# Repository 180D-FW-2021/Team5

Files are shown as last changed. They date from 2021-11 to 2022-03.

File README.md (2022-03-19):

# beep boop want to drive
**ECE 180D Team 5**: Derrick Huynh, David Kao, Robert Peralta, Lucas Wolter

## Overview
Beep boop want to drive is a reincarnation of the classic game
[Snake](https://en.wikipedia.org/wiki/Snake_(video_game_genre)), aiming to
bridge the gap between software and hardware in an engaging and entertaining
game. In beep boop want to drive, the user wirelessly steers a hardware car,
which they navigate around a game arena marked out in tape. There are several
dots placed in the arena and the user is directed to random dots in turn. The
user is provided 3 powerups, which they can use to cut the speed of the car in
half for 3 seconds, gaining a new powerup every 5 dots collected. Picking up a
dot increases the speed of the car up to maximum speed after 8 dots. The goal of
the game is to collect as many dots as possible without leaving the arena 3
times.

The game features a hardware, remote-controlled car, gesture recognition
steering, speech recognition game controls, and an overhead camera that uses
computer vision to track the game. A central laptop orchestrates the entire
game, seamlessly blending the disjoint modules together.

## Setup with Provided Hardware

### Game Arena

Take a white poster board and give it a border of black tape, leaving about a
1/2 inch gap between the tape and the edge of the poster board. Cut 4-5 squares
from a piece of black construction paper and tape them to the poster. Affix the
poster to the floor. Position the external camera directly over the poster such
that the entire poster is comfortably in view.

### Car

Make sure the `wpa_supplicant.conf` file is up to date with the wifi network and
password it will be using. Plug the power bank into the RPi and get its IP
address with

```
ping -4 raspberrypi.local
```

Then remotely `ssh` into the RPi and run the script:

```
ssh pi@<IP Address>
conda activate controller
python Team5/hardware/startCar.py
```
You can test if this is successful when running the main controller and having a successful handshake.

### IMU

Make sure the `wpa_supplicant.conf` file is up to date with the wifi network and
password it will be using. Attach the IMU RPi to the computer and log into it
with a serial connection. The necessary script will start automatically. Press
Ctrl+C to stop the script after finishing the game. If you need to restart the
script, run the following commands:

    cd Team5/gesture/BerryIMU/python-BerryIMU-gyro-accel-compass-filters
    python berryIMU.py

### Game Controller

Set up the controller environment with the following commands:

```
git clone https://github.com/180D-FW-2021/Team5.git
cd Team5/controller
conda env create -f environment.yml
conda activate controller
```
Then, ensuring that the external webcam is attached to the computer and
functional, find the computer's device handle indices with

```
python start.py --show-devices
```

To determine which of the listed camera indices is the correct one, test them
with commands like

```
python start.py --test-camera --camera <INDEX>
```

After finding the correct camera and microphone indices, start the game with

```
python start.py --camera <INDEX> --microphone <INDEX>
```

---
For full setup instructions and technical details, see the User Manual in
[`docs/README.md`](./docs/README.md).

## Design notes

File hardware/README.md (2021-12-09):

# Hardware
Code related to controlling and running the car

## `Car.__init__(in1, in2, in3, in4, enL, enR)`
The constructor of the `Car` class takes 6 parameters for the 4 input pins, and the 2 enable pins. The input pins control the direction of the motor and the enable pins control the speed.

Note: The enable pins MUST be PWM. On RPi, PWM are pins 12,13,18,19.

## `MQTT Commands`
### topic = `ece180d/team5/motorControls`

payload:

'L' - turns car left

'R' - turns car right

it works by running the motors in a different direction in a while loop for left(right)_turn_length seconds. This is a WIP as the length needs to be a function of the speed
after running in different direction, it then outputs the in pins to drive straight.

### topic = `ece180d/team5/speed`
the speed can only be between [20, 100]

payload:

'+' - increases the speed by 10%

'-' - decreases the speed by 10%

'#' (20 <= # <= 100) - sets custom speed at #%

### topic = `ece180d/team5/game`
Controls game functions

payload:

'game over' - stops the game and ends the script

'stop car' - stops the car and disables inputs (L/R)

'start car' - restarts car at previous speed

'activate power' - activates powerup that sets the speed to half the current speed. After 3 seconds, it returns to the old speed.

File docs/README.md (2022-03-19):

# User Manual
**ECE 180D Team 5**: Derrick Huynh, David Kao, Robert Peralta, Lucas Wolter

## Contents
1. [Overview](#overview)
1. [How to Play](#how-to-play)
1. [Setup with Provided Hardware](#setup-with-provided-hardware)
1. [Detailed Setup](#detailed-setup)

## Overview
Beep boop want to drive is a reincarnation of the classic game
[Snake](https://en.wikipedia.org/wiki/Snake_(video_game_genre)), aiming to
bridge the gap between software and hardware in an engaging and entertaining
game. In beep boop want to drive, the user wirelessly steers a hardware car,
which they navigate around a game arena marked out in tape. There are several
dots placed in the arena and the user is directed to random dots in turn. The
user is provided 3 powerups, which they can use to cut the speed of the car in
half for 3 seconds, gaining a new powerup every 5 dots collected. Picking up a
dot increases the speed of the car up to maximum speed after 8 dots. The goal of
the game is to collect as many dots as possible without leaving the arena 3
times.

The game features a hardware, remote-controlled car, gesture recognition
steering, speech recognition game controls, and an overhead camera that uses
computer vision to track the game. A central laptop orchestrates the entire
game, seamlessly blending the disjoint modules together.

## How to Play

* Hold the IMU controller with the USB cable pointing away from you. Tilt it
  left and right to steer. The car will only turn by a set amount
* Use voice commands to control the game:
    * `game pause`: stop the car and pause the game
    * `continue`: continue the game from a paused state
    * `activate power`: use a powerup, slowing the car down for a limited time
* Drive over the dot outlined in purple on the GUI to pick it up
* Every dot will increase the car's speed, and every 5 will give a new powerup
* If the car leaves the arena, you lose a life and game is paused. Move the car
  back into the arena and say `continue` to continue the game

## Setup with Provided Hardware

### Game Arena

Take a white poster board and give it a border of black tape, leaving about a
1/2 inch gap between the tape and the edge of the poster board. Cut 4-5 squares
from a piece of black construction paper and tape them to the poster. Affix the
poster to the floor. Position the external camera directly over the poster such
that the entire poster is comfortably in view.

### Car

Make sure the `wpa_supplicant.conf` file is up to date with the wifi network and
password it will be using. Plug the power bank into the RPi and get its IP
address with

```
ping -4 raspberrypi.local
```

Then remotely `ssh` into the RPi and run the script:

```
ssh pi@<IP Address>
conda activate controller
python Team5/hardware/startCar.py
```
You can test if this is successful when running the main controller and having a successful handshake.

### IMU

Make sure the `wpa_supplicant.conf` file is up to date with the wifi network and
password it will be using. Attach the IMU RPi to the computer and log into it
with a serial connection. The necessary script will start automatically. Press
Ctrl+C to stop the script after finishing the game. If you need to restart the
script, run the following commands:

    cd Team5/gesture/BerryIMU/python-BerryIMU-gyro-accel-compass-filters
    python berryIMU.py

### Game Controller

Set up the controller environment with the following commands:

```
git clone https://github.com/180D-FW-2021/Team5.git
cd Team5/controller
conda env create -f environment.yml
conda activate controller
```
Then, ensuring that the external webcam is attached to the computer and
functional, find the computer's device handle indices with

```
python start.py --show-devices
```

To determine which of the listed camera indices is the correct one, test them
with commands like

```
python start.py --test-camera --camera <INDEX>
```

After finding the correct camera and microphone indices, start the game with

```
python start.py --camera <INDEX> --microphone <INDEX>
```

## Detailed Setup
The game has 3 computers which all require different software running on them: the RPi with the IMU, the RPi on the car, and the controlling laptop. In total, you will need the following:

* Laptop (1)
* External webcam or smartphone (1)
  * If using a phone, you will need a camera mount to hold the phone over the game arena
* RaspberryPi Zero WH (2)
* BerryIMUv3 (1)
* 9V Battery
* 5V battery powerbank
* Hardware car
* White poster board
* Black paper (try to use non-reflective materials for all computer vision)
* Miscellaneous wires and connectors (Recommended to have ~8 Female-Male) OR a perfboard soldered with all necessary connections.

Note that the hardware car is not described in detail here. Currently we have no schematic of the car to share, but the car is based on an [L293 H-bridge](https://www.adafruit.com/product/807) and 2 9V DC motors, and an industrious user could investigate the code in the `hardware` directory to determine pin assignments on the RPi. Refer to the following info on how the H–Bridge works: [Direction Truth Table](https://drive.google.com/file/d/1n0UCoyRyvaSpgobGnBY8AHq8t6nLdRKh/view?usp=sharing), [H-Bridge Pinout](https://drive.google.com/file/d/1lcsleWE-I3sc4Y-wqP7EvscM3ZZQUWd-/view?usp=sharing).

### Arena
The arena has 3 main components: the boundary, the dots, and the car. These components are differentiated by their shape and color. The boundary is described by a black inset border on the poster, about a half inch from the edge, the dots are represented by solid black rectangles/squares, and the car is marked with a black circle. For the arena to be valid, there must be a white poster board with its black border, at least two dots, and the car fully within its bounds.

The arena is overseen by the external camera. This can be a standard webcam or a smartphone running [DroidCam](https://www.dev47apps.com/). Since this camera is likely not the default camera of the laptop, one will need to use the startup script described later to determine its device handle to ensure the game runs properly.

### Gesture RPi
These setup instructions are adapted from lab 4.
To setup the IMU controller, first connect the BerryIMU to the Raspberry Pi as shown:
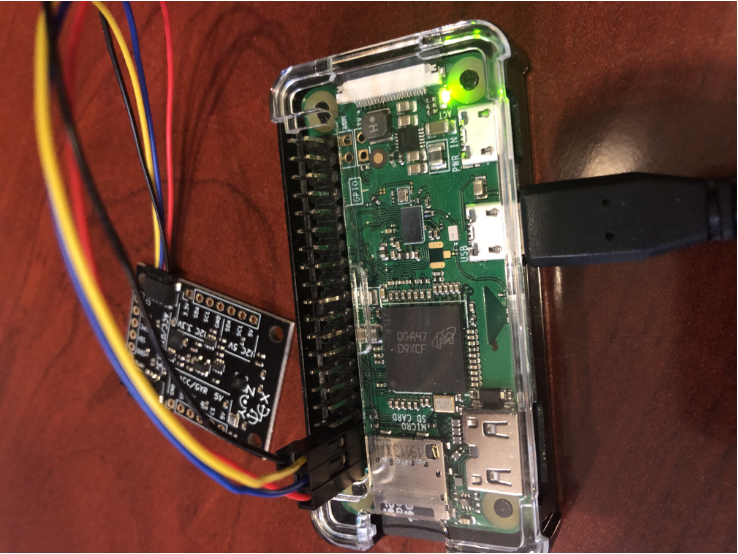
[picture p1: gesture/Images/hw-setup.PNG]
Connection between Raspberry Pi and BerryIMU


Next, enter the following commands into the Raspberry Pi command line to install the necessary components:

    sudo apt-get update
    sudo apt-get upgrade
    conda upgrade conda
    conda update conda
    pip install --upgrade pip
    sudo apt-get install git i2c-tools libi2c-dev
    conda install -c conda-forge smbus2

Try opening the blacklist file `/etc/modprobe.d/raspi-blacklist.conf`. If the file contains the line `blacklist i2c-bcm2708`, place a '#' in front to comment it out. If the file is empty or can't be opened then continue.

Add the following lines into `/etc/modules`:

    i2c-dev
    i2c-bcm2708

Add the following lines into `/boot/config.txt`:

    dtparam=i2c_arm=on
    dtparam=i2c1=on

Reboot the RPi, then enter in the command line `sudo i2cdetect -y 1`. The following should be displayed:
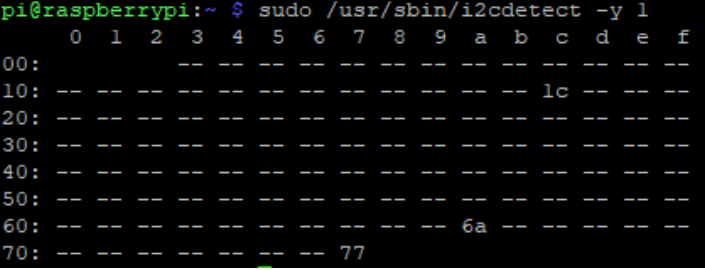
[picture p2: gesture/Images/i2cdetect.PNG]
Correct output for i2cdetect


Next, run `git clone https://github.com/180D-FW-2021/Team5.git` to clone the repository. Run the following commands to navigate to and run the IMU controller code. Always run IMU controller code before running Car RPi code. Press `Ctrl+C` to stop running IMU controller code.

    cd Team5/gesture/BerryIMU/python-BerryIMU-gyro-accel-compass-filters
    python berryIMU.py

### Car RPi
The only set up needed for the Car RPi is to connect to the internet by modifying the `wpa_supplicant.conf` file. Once connected, run `ifconfig` to obtain the IP address under the `WLAN0: inet`. Then enter the settings to enable remote ssh.

Then connect the RPi to the powerbank, then remote ssh and clone the repo.

    ssh pi@<ip address>
    git clone https://github.com/180D-FW-2021/Team5.git
    
Then go to the `Team5/hardware` folder. You may need to modify the file to change any pin assignments and MQTT topics as needed. Note that `enL` and `enR` MUST be PWM pins (pins 12,13,18,19)

    nano mqtt_motor.py
        in1 = ...
        in2 = ...
        etc.
    
The virtual environment provided in `controller/environment.yml` has all necessary packages to run the car software. Follow the steps in the Controller Laptop section to create the same environment on the Car RPi. Then activate the environment and run the main code.
    
    conda activate controller
    python Team5/hardware/startCar.py

Since the `controller` environment contains many large packages that the car will never use, you can also create a simpler environment, including only the `paho-mqtt` package.

    conda create -n <envname> -c conda-forge paho-mqtt
    conda activate <envname>
    python Team5/hardware/startCar.py

1. If your car responds to messages that your controller did not send, make sure that you are not responding to other messages on the same mqtt topic. If this occurs, please change the topic on all MQTT programs. 
2. If you suddenly lose connection to the car, it is possible that the car left the range of the remote ssh. Because of the heartbeat, the car should be perfectly fine running the script remotely and can stop itself. 

### Game Controller
(*This laptop needs a microphone in order to process speech inputs.*)

Follow the instructions in [Setup with Provided Hardware](#setup-with-provided-hardware).

The GUI will display information about the game parts it has parsed. The boundary will be outlined in blue, the dots will have green circles around them, and the car will be outlined in red. The target dot, the next dot the player should aim to get, will have an extra purple circle around it.

The basic GUI is split into two halves. The left half is the camera view, augmented with callouts of the arena boundary, the targets, the current objective, and the location of the car. The right half contains the start button and five text labels. The start button allows the controller to scan the arena and prepare the camera to track the game. The five text labels are, in order: the current game state (running, paused); the player's score, number of lives, number of powerups, and the tooltip. The tooltip changes dynamically based on the current game state. Several of the labels also flash red when appropriate. There are also two buttons at the bottom of the right half that replicate the voice command functions (see `Team5/speech`.) The first one is "continue/pause" and the second one is "activate power."

After the game ends, the GUI will prompt you for your name. Enter your name and go to `beepboopdrive.fun` to view your score on the leaderboard.

Running `start.py` may fail with an error about a license expiring. Because this project uses the free version of [Porcupine](https://picovoice.ai/platform/porcupine/), the speech recognition models eventually expire. If a user so desires, they could train a new model of the same keywords and place the model in `speech/porcupine_models`. The user would also have to change the file paths in [`controller/speechworker.py`](../controller/speechworker.py).

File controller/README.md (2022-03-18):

# Game Controller
Contains the central game controller code. The game controller manages game state and runs the GUI, as well as manages the speech recognition and computer vision modules.

## Speech
The speech recognition module, `speechworker.py` is adapted from the Porucupine demo found in `Team5/speech`. The base paths of the models need to be specified and should be updated monthly because they expire. The access key from Picovoice Console also needs to be provided.

The class inherits from a [PyQt Qthread](https://doc.qt.io/qtforpython/PySide6/QtCore/QThread.html) object to ensure compatibility with the GUI (so it doesn't freeze while listening for keywords). 

## GUI
The GUI uses PyQT5. Install using 

```
pip install PyQt5
```

`cameraworker.py` and `speechworker.py` have been adapted to emit pyqtSignals which don't block threads. This allows them to collect and pass information to the GUI without freezing or crashing the GUI. These signals are passed into "slots", which are similar to event handlers natively attached to GUI elements.

The basic GUI is split into two halves. The left half is the camera view, augmented with callouts of the arena boundary, the targets, the current objective, and the location of the car. The right half contains the start button and five text labels. The start button allows the controller to scan the arena and prepare the camera to track the game. The five text labels are, in order: the current game state (running, paused); the player's score, number of lives, number of powerups, and the tooltip. The tooltip changes dynamically based on the current game state. Several of the labels also flash red when appropriate. There are also two buttons at the bottom of the right half that replicate the voice command functions (see `Team5/speech`.) The first one is "continue/pause" and the second one is "activate power."

After the game ends, the GUI will prompt you for your name. Enter your name and go to `beepboopdrive.fun` to view your score on the leaderboard.



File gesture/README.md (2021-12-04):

# Gesture Recognition
Code related to IMU gesture recognition.

### How to run code:

Download git repository to a Raspberry Pi.

Run the following in terminal:

`cd Team5/gesture/BerryIMU/python-BerryIMU-gyro-accel-compass-filters`

`python berryIMU.py`

Press `Ctrl+C` to stop running the code when finished.

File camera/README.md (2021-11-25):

# Computer Vision
Defines the `Overhead` class in `overhead.py`, which wraps all computer vision functionality. `Overhead` provides functions to find the game boundary and dots, as well as track car motion and detect if the car leaves the boundary or picks up a dot.

## `Overhead.__init__(threshold)`
The constructor of the `Overhead` class takes a single parameter, which is the minimum area for a dot. Any contours of the dot color that have an area smaller than this value will be ignored. Generally, this value is on the order of 100s, but it will depend on the final height of the camera above the game arena.

## `Overhead.setup()`
Parses the game arena, finding the game boundary and all dots in the arena. This only accepts dots that have a contour area greater than the threshold given at construction. `setup()` should only be called once the game arena is set up and the camera is steady. A call to `setup()` will set `self.boundary` with the smoothed contour of the boundary, `self.dots` with a list of bounding circles of the dots found, and `self.nDots` with `len(self.dots)`.

## `Overhead.loop(target)`
The main game loop function, which should be called continuously. `loop()` takes a single parameter: the index of the current target dot. The target index must be between 0 inclusive and `Overhead.nDots` exclusive. The target index is not expected to change until the car collects the dot.

Returns the tuple `(inBoundary, gotTarget)`, where `inBoundary` is `True` if the car is still inside the game boundary and `gotTarget` is `True` if the car has collected the target on this frame. If `gotTarget` is `True`, then the target index should change before the next call to `loop()`.

## `Overhead.drawFrame(target=True, dots=True, car=False, boundary=False)`
Uses OpenCV functions to draw requested objects on the current frame and returns the modified frame in the RGB color space. By default, `drawFrame()` will only include the dots and place an extra circle around the target dot, but it can also draw the car and the game boundary if requested.

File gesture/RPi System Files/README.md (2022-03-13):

These are RPi system files that I edited in an attempt to autostart the IMU script when the RPi powers on.

imu_startup.service is located in /etc/systemd/system/ on the RPi. I was unable to get this service working.

.bashrc is located in /home/pi/ on the RPi. I added the last two lines so the IMU script starts immediately after logging into the RPi.

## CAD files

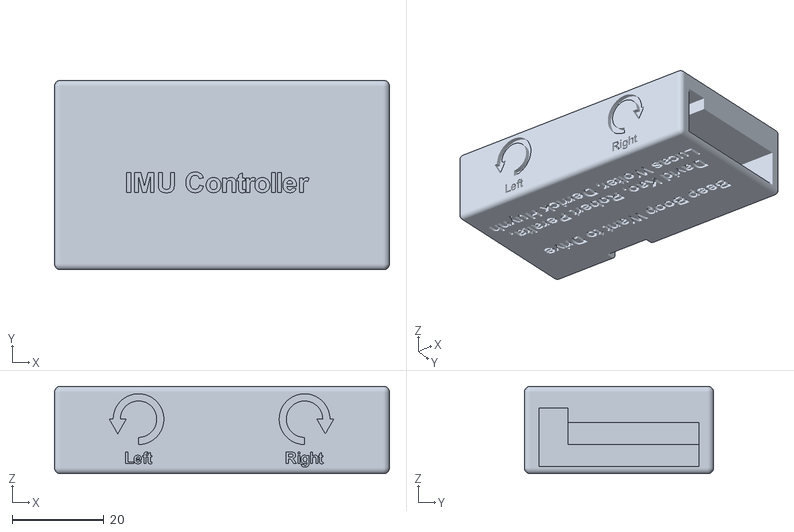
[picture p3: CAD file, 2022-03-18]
gesture/IMU model.stl
73.0 x 41.3 x 19.0

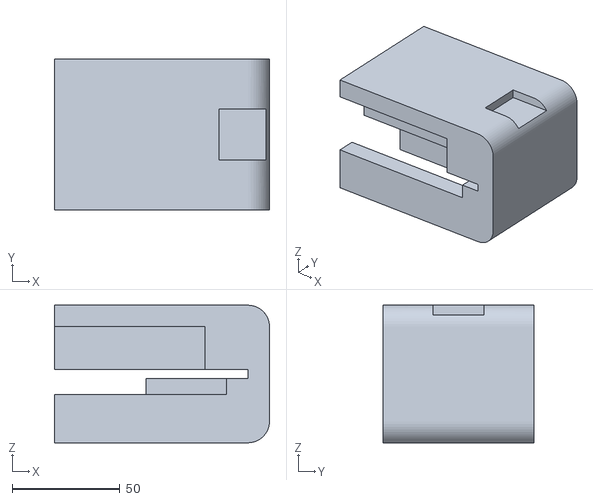
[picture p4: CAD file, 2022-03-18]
hardware/Car Model.stl
100.0 x 70.0 x 64.0

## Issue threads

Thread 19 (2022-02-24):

gui improvements required

davidkao41, 2022-02-24:
1. game end - need popup to input user name
2. info - score, powerups, turns, survived time (game time), current datetime
turns - not super required, but could be fun - needs data from imu
datetime - already implemented in leaderboard
3. turn into json and make http post
in derrick/website/Team5/website/backend/tester.py

derrickkhuynh, 2022-03-03:
#25

last 2 commits of this are what's important.

davidkao41, 2022-03-03:
commited everything besides the turns

davidkao41, 2022-03-13:
ADDED TURNS

Closed 2022-03-13.

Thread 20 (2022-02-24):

restart game from gui

davidkao41, 2022-02-24:
1. need to check if camera/game/mqtt is started in startGame() -> simple check with .active member
2. need to move initialization of game variables into startGame() -> just reset them, still initialize in GUI

Closed 2022-03-02.

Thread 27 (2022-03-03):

Make sure camera doesn't collect dots while game is paused

robertnperalta, 2022-03-03:

Closed 2022-03-13.

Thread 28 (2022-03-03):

GUI crashes on gaining powerup

robertnperalta, 2022-03-03:
Error:

```
Traceback (most recent call last):
  File "C:\Users\rober\Robert\School\UCLA\Year 4\Fall\EE 180D\Team5\controller\controller.py", line 239, in <lambda>
    self.timer.singleShot(1000, lambda x=label: x.setStyleSheet("QLabel {background-color: red;}"))
AttributeError: 'int' object has no attribute 'setStyleSheet'
```

Closed 2022-03-07.

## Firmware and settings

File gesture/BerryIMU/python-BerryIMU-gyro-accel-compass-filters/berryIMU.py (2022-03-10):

#!/usr/bin/python
#
#    This program  reads the angles from the acceleromteer, gyroscope
#    and mangnetometer on a BerryIMU connected to a Raspberry Pi.
#
#    This program includes two filters (low pass and median) to improve the
#    values returned from BerryIMU by reducing noise.
#
#    The BerryIMUv1, BerryIMUv2 and BerryIMUv3 are supported
#
#    This script is python 2.7 and 3 compatible
#
#    Feel free to do whatever you like with this code.
#    Distributed as-is; no warranty is given.
#
#    http://ozzmaker.com/



import sys
import time
import math
import IMU
import datetime
import os


RAD_TO_DEG = 57.29578
M_PI = 3.14159265358979323846
G_GAIN = 0.070          # [deg/s/LSB]  If you change the dps for gyro, you need to update this value accordingly
AA =  0.40              # Complementary filter constant
MAG_LPF_FACTOR = 0.4    # Low pass filter constant magnetometer
ACC_LPF_FACTOR = 0.4    # Low pass filter constant for accelerometer
ACC_MEDIANTABLESIZE = 9         # Median filter table size for accelerometer. Higher = smoother but a longer delay
MAG_MEDIANTABLESIZE = 9         # Median filter table size for magnetometer. Higher = smoother but a longer delay



################# Compass Calibration values ############
# Use calibrateBerryIMU.py to get calibration values
# Calibrating the compass isnt mandatory, however a calibrated
# compass will result in a more accurate heading value.

magXmin =  0
magYmin =  0
magZmin =  0
magXmax =  0
magYmax =  0
magZmax =  0


'''
Here is an example:
magXmin =  -1748
magYmin =  -1025
magZmin =  -1876
magXmax =  959
magYmax =  1651
magZmax =  708
Dont use the above values, these are just an example.
'''
############### END Calibration offsets #################


#Kalman filter variables
Q_angle = 0.02
Q_gyro = 0.0015
R_angle = 0.005
y_bias = 0.0
x_bias = 0.0
XP_00 = 0.0
XP_01 = 0.0
XP_10 = 0.0
XP_11 = 0.0
YP_00 = 0.0
YP_01 = 0.0
YP_10 = 0.0
YP_11 = 0.0
KFangleX = 0.0
KFangleY = 0.0



def kalmanFilterY ( accAngle, gyroRate, DT):
    y=0.0
    S=0.0

    global KFangleY
    global Q_angle
    global Q_gyro
    global y_bias
    global YP_00
    global YP_01
    global YP_10
    global YP_11

    KFangleY = KFangleY + DT * (gyroRate - y_bias)

    YP_00 = YP_00 + ( - DT * (YP_10 + YP_01) + Q_angle * DT )
    YP_01 = YP_01 + ( - DT * YP_11 )
    YP_10 = YP_10 + ( - DT * YP_11 )
    YP_11 = YP_11 + ( + Q_gyro * DT )

    y = accAngle - KFangleY
    S = YP_00 + R_angle
    K_0 = YP_00 / S
    K_1 = YP_10 / S

    KFangleY = KFangleY + ( K_0 * y )
    y_bias = y_bias + ( K_1 * y )

    YP_00 = YP_00 - ( K_0 * YP_00 )
    YP_01 = YP_01 - ( K_0 * YP_01 )
    YP_10 = YP_10 - ( K_1 * YP_00 )
    YP_11 = YP_11 - ( K_1 * YP_01 )

    return KFangleY

def kalmanFilterX ( accAngle, gyroRate, DT):
    x=0.0
    S=0.0

    global KFangleX
    global Q_angle
    global Q_gyro
    global x_bias
    global XP_00
    global XP_01
    global XP_10
    global XP_11


    KFangleX = KFangleX + DT * (gyroRate - x_bias)

    XP_00 = XP_00 + ( - DT * (XP_10 + XP_01) + Q_angle * DT )
    XP_01 = XP_01 + ( - DT * XP_11 )
    XP_10 = XP_10 + ( - DT * XP_11 )
    XP_11 = XP_11 + ( + Q_gyro * DT )

    x = accAngle - KFangleX
    S = XP_00 + R_angle
    K_0 = XP_00 / S
    K_1 = XP_10 / S

    KFangleX = KFangleX + ( K_0 * x )
    x_bias = x_bias + ( K_1 * x )

    XP_00 = XP_00 - ( K_0 * XP_00 )
    XP_01 = XP_01 - ( K_0 * XP_01 )
    XP_10 = XP_10 - ( K_1 * XP_00 )
    XP_11 = XP_11 - ( K_1 * XP_01 )

    return KFangleX


gyroXangle = 0.0
gyroYangle = 0.0
gyroZangle = 0.0
CFangleX = 0.0
CFangleY = 0.0
CFangleXFiltered = 0.0
CFangleYFiltered = 0.0
kalmanX = 0.0
kalmanY = 0.0
oldXMagRawValue = 0
oldYMagRawValue = 0
oldZMagRawValue = 0
oldXAccRawValue = 0
oldYAccRawValue = 0
oldZAccRawValue = 0

a = datetime.datetime.now()



#Setup the tables for the mdeian filter. Fill them all with '1' so we dont get devide by zero error
acc_medianTable1X = [1] * ACC_MEDIANTABLESIZE
acc_medianTable1Y = [1] * ACC_MEDIANTABLESIZE
acc_medianTable1Z = [1] * ACC_MEDIANTABLESIZE
acc_medianTable2X = [1] * ACC_MEDIANTABLESIZE
acc_medianTable2Y = [1] * ACC_MEDIANTABLESIZE
acc_medianTable2Z = [1] * ACC_MEDIANTABLESIZE
mag_medianTable1X = [1] * MAG_MEDIANTABLESIZE
mag_medianTable1Y = [1] * MAG_MEDIANTABLESIZE
mag_medianTable1Z = [1] * MAG_MEDIANTABLESIZE
mag_medianTable2X = [1] * MAG_MEDIANTABLESIZE
mag_medianTable2Y = [1] * MAG_MEDIANTABLESIZE
mag_medianTable2Z = [1] * MAG_MEDIANTABLESIZE

IMU.detectIMU()     #Detect if BerryIMU is connected.
if(IMU.BerryIMUversion == 99):
    print(" No BerryIMU found... exiting ")
    sys.exit()
IMU.initIMU()       #Initialise the accelerometer, gyroscope and compass

############################ MQTT PUBLISHER SETUP ####################

import paho.mqtt.client as mqtt

def on_connect(client, userdata, flags, rc):
	print("Connection returned result: "+str(rc))
	client.subscribe("ece180d/team5/imuReady", qos=1)
	
def on_disconnect(client, userdata, rc):
	if rc != 0:
		print('Unexpected Disconnect')
	else:
		print('Expected Disconnect')

# handshake with game controller to start game		
def on_message(client, userdata, message):
	print('Received message: "' + str(message.payload) + '" on topic "' + message.topic + '" with QoS ' + str(message.qos))
	payload = message.payload.decode("utf-8")
	if payload == '?':
		client.publish(readyString, readyChar, qos=1)

client = mqtt.Client()
client.on_connect = on_connect
client.on_disconnect = on_disconnect
client.on_message = on_message
client.connect_async('test.mosquitto.org')

client.loop_start()

mqttString = 'ece180d/team5/motorControls'
readyString = 'ece180d/team5/imuReady'
turnChar = 'S'
readyChar = 'R'

client.publish(mqttString, turnChar, qos=1)

#########################################################################

while True:

    #Read the accelerometer,gyroscope and magnetometer values
    ACCx = IMU.readACCx()
    ACCy = IMU.readACCy()
    ACCz = IMU.readACCz()
    GYRx = IMU.readGYRx()
    GYRy = IMU.readGYRy()
    GYRz = IMU.readGYRz()
    MAGx = IMU.readMAGx()
    MAGy = IMU.readMAGy()
    MAGz = IMU.readMAGz()


    #Apply compass calibration
    MAGx -= (magXmin + magXmax) /2
    MAGy -= (magYmin + magYmax) /2
    MAGz -= (magZmin + magZmax) /2


    ##Calculate loop Period(LP). How long between Gyro Reads
    b = datetime.datetime.now() - a
    a = datetime.datetime.now()
    LP = b.microseconds/(1000000*1.0)
    outputString = "Loop Time %5.2f " % ( LP )



    ###############################################
    #### Apply low pass filter ####
    ###############################################
    MAGx =  MAGx  * MAG_LPF_FACTOR + oldXMagRawValue*(1 - MAG_LPF_FACTOR);
    MAGy =  MAGy  * MAG_LPF_FACTOR + oldYMagRawValue*(1 - MAG_LPF_FACTOR);
    MAGz =  MAGz  * MAG_LPF_FACTOR + oldZMagRawValue*(1 - MAG_LPF_FACTOR);
    ACCx =  ACCx  * ACC_LPF_FACTOR + oldXAccRawValue*(1 - ACC_LPF_FACTOR);
    ACCy =  ACCy  * ACC_LPF_FACTOR + oldYAccRawValue*(1 - ACC_LPF_FACTOR);
    ACCz =  ACCz  * ACC_LPF_FACTOR + oldZAccRawValue*(1 - ACC_LPF_FACTOR);

    oldXMagRawValue = MAGx
    oldYMagRawValue = MAGy
    oldZMagRawValue = MAGz
    oldXAccRawValue = ACCx
    oldYAccRawValue = ACCy
    oldZAccRawValue = ACCz

    #########################################
    #### Median filter for accelerometer ####
    #########################################
    # cycle the table
    for x in range (ACC_MEDIANTABLESIZE-1,0,-1 ):
        acc_medianTable1X[x] = acc_medianTable1X[x-1]
        acc_medianTable1Y[x] = acc_medianTable1Y[x-1]
        acc_medianTable1Z[x] = acc_medianTable1Z[x-1]

    # Insert the lates values
    acc_medianTable1X[0] = ACCx
    acc_medianTable1Y[0] = ACCy
    acc_medianTable1Z[0] = ACCz

    # Copy the tables
    acc_medianTable2X = acc_medianTable1X[:]
    acc_medianTable2Y = acc_medianTable1Y[:]
    acc_medianTable2Z = acc_medianTable1Z[:]

    # Sort table 2
    acc_medianTable2X.sort()
    acc_medianTable2Y.sort()
    acc_medianTable2Z.sort()

    # The middle value is the value we are interested in
    ACCx = acc_medianTable2X[int(ACC_MEDIANTABLESIZE/2)];
    ACCy = acc_medianTable2Y[int(ACC_MEDIANTABLESIZE/2)];
    ACCz = acc_medianTable2Z[int(ACC_MEDIANTABLESIZE/2)];



    #########################################
    #### Median filter for magnetometer ####
    #########################################
    # cycle the table
    for x in range (MAG_MEDIANTABLESIZE-1,0,-1 ):
        mag_medianTable1X[x] = mag_medianTable1X[x-1]
        mag_medianTable1Y[x] = mag_medianTable1Y[x-1]
        mag_medianTable1Z[x] = mag_medianTable1Z[x-1]

    # Insert the latest values
    mag_medianTable1X[0] = MAGx
    mag_medianTable1Y[0] = MAGy
    mag_medianTable1Z[0] = MAGz

    # Copy the tables
    mag_medianTable2X = mag_medianTable1X[:]
    mag_medianTable2Y = mag_medianTable1Y[:]
    mag_medianTable2Z = mag_medianTable1Z[:]

    # Sort table 2
    mag_medianTable2X.sort()
    mag_medianTable2Y.sort()
    mag_medianTable2Z.sort()

    # The middle value is the value we are interested in
    MAGx = mag_medianTable2X[int(MAG_MEDIANTABLESIZE/2)];
    MAGy = mag_medianTable2Y[int(MAG_MEDIANTABLESIZE/2)];
    MAGz = mag_medianTable2Z[int(MAG_MEDIANTABLESIZE/2)];



    #Convert Gyro raw to degrees per second
    rate_gyr_x =  GYRx * G_GAIN
    rate_gyr_y =  GYRy * G_GAIN
    rate_gyr_z =  GYRz * G_GAIN


    #Calculate the angles from the gyro.
    gyroXangle+=rate_gyr_x*LP
    gyroYangle+=rate_gyr_y*LP
    gyroZangle+=rate_gyr_z*LP

    #Convert Accelerometer values to degrees
    AccXangle =  (math.atan2(ACCy,ACCz)*RAD_TO_DEG)
    AccYangle =  (math.atan2(ACCz,ACCx)+M_PI)*RAD_TO_DEG


    #Change the rotation value of the accelerometer to -/+ 180 and
    #move the Y axis '0' point to up.  This makes it easier to read.
    if AccYangle > 90:
        AccYangle -= 270.0
    else:
        AccYangle += 90.0



    #Complementary filter used to combine the accelerometer and gyro values.
    CFangleX=AA*(CFangleX+rate_gyr_x*LP) +(1 - AA) * AccXangle
    CFangleY=AA*(CFangleY+rate_gyr_y*LP) +(1 - AA) * AccYangle

    #Kalman filter used to combine the accelerometer and gyro values.
    kalmanY = kalmanFilterY(AccYangle, rate_gyr_y,LP)
    kalmanX = kalmanFilterX(AccXangle, rate_gyr_x,LP)

    #Calculate heading
    heading = 180 * math.atan2(MAGy,MAGx)/M_PI

    #Only have our heading between 0 and 360
    if heading < 0:
        heading += 360

    ####################################################################
    ###################Tilt compensated heading#########################
    ####################################################################
    #Normalize accelerometer raw values.
    accXnorm = ACCx/math.sqrt(ACCx * ACCx + ACCy * ACCy + ACCz * ACCz)
    accYnorm = ACCy/math.sqrt(ACCx * ACCx + ACCy * ACCy + ACCz * ACCz)


    #Calculate pitch and roll
    pitch = math.asin(accXnorm)
    roll = -math.asin(accYnorm/math.cos(pitch))


    #Calculate the new tilt compensated values
    #The compass and accelerometer are orientated differently on the the BerryIMUv1, v2 and v3.
    #This needs to be taken into consideration when performing the calculations

    #X compensation
    if(IMU.BerryIMUversion == 1 or IMU.BerryIMUversion == 3):            #LSM9DS0 and (LSM6DSL & LIS2MDL)
        magXcomp = MAGx*math.cos(pitch)+MAGz*math.sin(pitch)
    else:                                                                #LSM9DS1
        magXcomp = MAGx*math.cos(pitch)-MAGz*math.sin(pitch)

    #Y compensation
    if(IMU.BerryIMUversion == 1 or IMU.BerryIMUversion == 3):            #LSM9DS0 and (LSM6DSL & LIS2MDL)
        magYcomp = MAGx*math.sin(roll)*math.sin(pitch)+MAGy*math.cos(roll)-MAGz*math.sin(roll)*math.cos(pitch)
    else:                                                                #LSM9DS1
        magYcomp = MAGx*math.sin(roll)*math.sin(pitch)+MAGy*math.cos(roll)+MAGz*math.sin(roll)*math.cos(pitch)





    #Calculate tilt compensated heading
    tiltCompensatedHeading = 180 * math.atan2(magYcomp,magXcomp)/M_PI

    if tiltCompensatedHeading < 0:
        tiltCompensatedHeading += 360


    ##################### END Tilt Compensation ########################


    if 1:                       #Change to '0' to stop showing the angles from the accelerometer
        outputString += "#  ACCX Angle %5.2f ACCY Angle %5.2f  #  " % (AccXangle, AccYangle)

    if 1:                       #Change to '0' to stop  showing the angles from the gyro
        outputString +="\t# GRYX Angle %5.2f  GYRY Angle %5.2f  GYRZ Angle %5.2f # " % (gyroXangle,gyroYangle,gyroZangle)

    if 1:                       #Change to '0' to stop  showing the angles from the complementary filter
        outputString +="\t#  CFangleX Angle %5.2f   CFangleY Angle %5.2f  #" % (CFangleX,CFangleY)

    if 1:                       #Change to '0' to stop  showing the heading
        outputString +="\t# HEADING %5.2f  tiltCompensatedHeading %5.2f #" % (heading,tiltCompensatedHeading)

    if 1:                       #Change to '0' to stop  showing the angles from the Kalman filter
        outputString +="# kalmanX %5.2f   kalmanY %5.2f #" % (kalmanX,kalmanY)

    print(outputString)

    ############################# MQTT PUBLISH ########################

    # hearbeat
    #client.publish(readyString, readyChar, qos=1)

    if AccXangle < -40 and turnChar != 'L':
        turnChar = 'L'
        client.publish(mqttString, turnChar, qos=1)
    elif AccXangle >= -40 and AccXangle <= 40 and turnChar != 'S':
        turnChar = 'S'
        #client.publish(mqttString, turnChar, qos=1)
    elif AccXangle > 40 and turnChar != 'R':
        turnChar = 'R'
        client.publish(mqttString, turnChar, qos=1)

    ###################################################################

    #slow program down a bit, makes the output more readable
    time.sleep(0.03)

################# MQTT PUBLISHER DISCONNECT ######################

client.loop_stop()
client.disconnect()

####################################################################

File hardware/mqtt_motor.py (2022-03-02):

import paho.mqtt.client as mqtt
import RPi.GPIO as io
import time
from car import Car

game_over = False
powerup_on = False
time_powerup = 0
old_speed = 20

#set up motor pins and en pins. 12,13,18,19 are PWM. We use PWM to control the motor speed on enR and enL.
in1 = 17
in2 = 27
in3 = 23
in4 = 24
enR = 13
enL = 19

car = Car(in1, in2, in3, in4, enR, enL)

def on_connect(client, userdata, flags, rc):
	print("Connection returned result: "+str(rc))

	client.subscribe("ece180d/team5/#", qos=1)

def on_disconnect(client, userdata, rc):
	if rc != 0:
		print("Unexpected Disconnect")
	else:
		print("Expected Disconnect")

def on_message(client, userdata, message):
	global car
	print("Received message:")
	payload = message.payload.decode("utf-8")
	print(payload)
	if(str(message.topic) == 'ece180d/team5/motorControls'):
		if(car.is_stopped == True):
			print('Car is stopped')
		elif(payload == 'L'):
			car.turn_Left()
		elif(payload == 'R'):
			car.turn_Right()
		elif(payload == 'S'):
			pass
		else:
			print('Unknown direction control command')
	elif(str(message.topic) == 'ece180d/team5/speed'):
		if(payload == '+'):
			car.change_Speed(min(car.speed + 10, 100))
		elif(payload == '-'):
			car.change_Speed(max(car.speed - 10, 20))
		else:
			try:
				temp = int(payload)
				if(temp >= 20 and temp <= 100):
					car.change_Speed(temp)
				else:
					print('invalid input speed. It must be between [20, 100]')
			except:
				print('Unknown speed command')
	elif(str(message.topic) == 'ece180d/team5/game'):
		global game_over
		global powerup_on
		global time_powerup
		global old_speed
		if(payload == 'game over'):
			game_over = True
		elif(payload == 'stop car'):
			car.is_stopped = True
			car.stop_Driving()
		elif(payload == 'start car'):
			car.is_stopped = False
			car.start_Driving()
		elif(payload == 'activate power'):
			powerup_on = True
			time_powerup = time.time()
			#grab the old speed before it's changed
			old_speed = car.speed
			#change to speed to half of the old speed (or 20 minimum)
			car.change_Speed(max(old_speed/2, 20))

client = mqtt.Client()

client.on_connect = on_connect
client.on_disconnect = on_disconnect
client.on_message = on_message

#client.connect_async('mqtt.eclipseprojects.io')
client.connect_async('test.mosquitto.org')
client.loop_start()

try:
	while(True):
		while(not(game_over)):
			#if powerup is on, and it's been 3 seconds
			if(powerup_on == True and time.time() - time_powerup >= 3):
				powerup_on = False
				car.change_Speed(old_speed)
				print('Powerup over')
		car.reset()
		game_over = False
		powerup_on = False
		time_powerup = 0
		old_speed = 20
except KeyboardInterrupt:
	io.cleanup()
	client.loop_stop()
	client.disconnect()

io.cleanup()
client.loop_stop()
client.disconnect()

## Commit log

2021-11-11 add porcupine demo + timer
2021-11-11 add speech_recognition demo+timer
2021-11-18 add motor control script
2021-11-18 IMU code
2021-11-18 changed values of motor turning
2021-11-18 add Activate power keyword detection
2021-11-18 add activate power keyword
2021-11-24 Move current frame into a member variable
2021-11-25 add pwm speed control test
2021-11-29 add game conditions (stop/start/over) and powerups
2021-11-30 add activate power command
2021-12-01 Clarify imports for camera worker
2021-12-02 add powerup code
2021-12-02 Add debug prints
2021-12-02 change power up speeds to half current speed
2021-12-03 Only react to camera if game isn't paused
2021-12-04 add test prints
2021-12-05 no longer publishes 'S' on straight movement
    [berryIMU.py]
2021-12-05 Implement powerup
2021-12-05 Re-enable activate-power keyword
2021-12-09 Add None checks on thread shutdown
2022-01-30 change mqtt broker to test.mosquitto.org
    [berryIMU.py]
2022-02-19 Add wrapper to show connected devices
2022-02-19 Print camera indices with names
2022-02-19 Add argument to test camera output
2022-02-19 Update code to pass in device indices
2022-02-24 add reset stuff so car script doesnt end at game over
    [car.py, mqtt_motor.py]
2022-02-24 fix bug w PWM on reset
    [car.py]
2022-02-24 Remove old test print
2022-03-02 issue #22: more powerups
2022-03-03 add IMU ready heartbeat
2022-03-03 idk what broke but this should be fixed idk
    [mqtt_motor.py]
2022-03-03 add buttons for voice functionality
2022-03-03 Add a couple big fixes
2022-03-03 bruh like a million warnings
2022-03-04 Improve printing for handshake
2022-03-10 Attach heartbeat to timer
2022-03-10 bug fixing w numTurns
    [startCar.py]
2022-03-10 Remove old print
2022-03-10 fix debugging print line
    [startCar.py]
2022-03-10 Freeze cameraworker when pushing to leaderboard
2022-03-10 add imu ready handshake
2022-03-10 Add pausing to cameraworker
2022-03-10 Pause cameraworker when game is paused
2022-03-14 fix heartbeat stuff again
    [startCar.py]
2022-03-14 handle edge case where car gets dot during powerup
2022-03-14 upload 3d models for car and IMU
    [Car Model.stl, IMU model.stl]
2022-03-18 Update IMU section
